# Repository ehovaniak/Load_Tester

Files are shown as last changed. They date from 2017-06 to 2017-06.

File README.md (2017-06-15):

# Load_Tester
This repository contains files and software for a variable load PCB for external load testing and characterization.

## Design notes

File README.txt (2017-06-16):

This repository contains schematics, layout, software, and other data pertaining a siimple load 
testing board I had designed for IV characterization.

This is one of the earliest boards I have designed and manufactured. Load is distrubuted through a 
10-step resistor ladder network. My original implementation adjusts the resistor ladder in a binary 
fashion, allowing for a constant linear increase in current to be drawn from the load. The current 
and voltage are measured by the INA226 IC. Data is managed and transferred over USB to the host 
computer.

I wrote a compaion Python applicaton to interface with the board to adjust load settings manually. I 
also wrote a test function in the app. The test would vary the load from least to greatest and take 
measurements with each load change. Upon completion, the app would plot this data as an IV curve and 
display to the user. The data could also be saved to a .CSV file if desired.

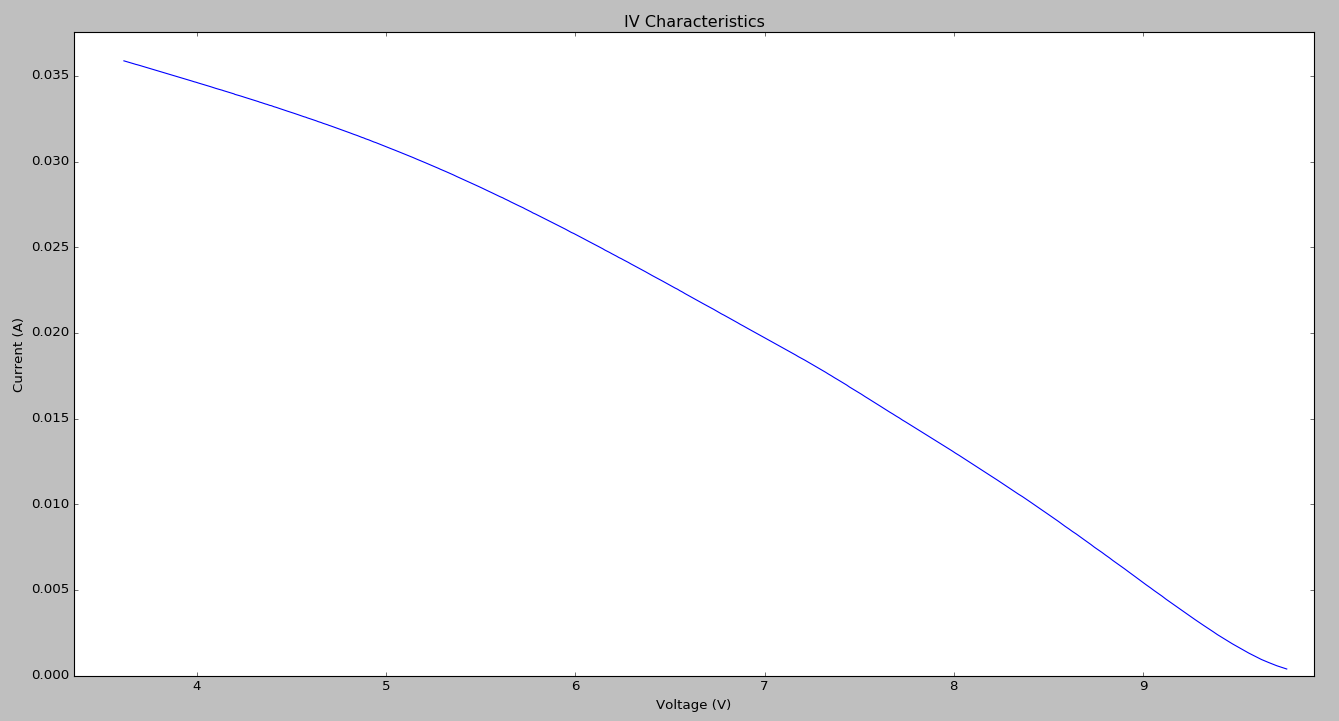
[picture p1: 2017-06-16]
IV_Curve_Example.png

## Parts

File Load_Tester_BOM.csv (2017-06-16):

Designator | Quantity | Description | Manufacturer | Manufacturer Part Number | Supplier | Supplier Part Number
C1 | 1 | CAP CER 4.7UF 35V X5R 0603 | TDK | C1608X5R1V475K080AC | Digi-Key | 445-9064-1-ND
C2 | 1 | CAP CER 22UF 10V X5R 0603 | TDK | C1608X5R1A226M080AC | Digi-Key | 445-9077-1-ND
C3, C5, C10, C14, C16 | 5 | CAP CER 0.1UF 25V X7R 0402 | TDK | C1005X7R1E104K050BB | Digi-Key | 445-7348-1-ND
C4 | 1 | CAP CER 0.1UF 25V X7R 0603 | TDK | C1608X7R1E104K080AA | Digi-Key | 445-1316-1-ND
C6 | 1 | CAP CER 1000PF 50V X7R 0603 | TDK | C1608X7R1H102K080AE | Digi-Key | 445-15923-1-ND
C7 | 1 | CAP CER 10000PF 50V X7R 0603 | TDK | C1608X7R1H103K080AA | Digi-Key | 445-1311-1-ND
C8, C9 | 2 | CAP CER 47PF 50V C0G 0603 | TDK | C1608C0G1H470J080AA | Digi-Key | 445-1277-1-ND
C11, C12 | 2 | CAP CER 18PF 50V C0G 0603 | TDK | CGJ3E2C0G1H180J080AA | Digi-Key | 445-13325-1-ND
C13 | 1 | CAP CER 0.47UF 10V X5R 0402 | TDK | C1005X5R1A474K050BB | Digi-Key | 445-4989-1-ND
C15 | 1 | CAP CER 10UF 10V JB 0603 | TDK | C1608JB1A106K080AC | Digi-Key | 445-11201-1-ND
C17 | 1 | CAP CER 4.7UF 10V X5R 0402 | TDK | C1005X5R1A475K050BC | Digi-Key | 445-13820-1-ND
D1, D2 | 2 | LED SMARTLED GREEN 570NM 0603 | OSRAM Opto Semiconductors | LG L29K-G2J1-24-Z | Digi-Key | 475-2709-1-ND
D3, D4, D5, D6, D7, D8, D9, D10, D11, D12 | 10 | LED SMARTLED RED 630NM 0603 SMD | OSRAM Opto Semiconductors | LS L29K-H1J2-1-Z | Digi-Key | 475-1195-1-ND
J1 | 1 | CONNECTOR MICRO USB B RECPT BTTM MOUNT ASSY | Molex | 47346-0001 | Mouser | 538-47346-0001
J2 | 1 | IDC BOX HEADER 0.050 10 POS | CNC Tech | 3220-10-0300-00 | Digi-Key | 1175-1629-ND
L1, L2 | 2 | FERRITE CHIP 1000 OHM 300MA 0402 | Samsung | CIM05U102NC | Digi-Key | 1276-6336-2-ND
Q1, Q2, Q3, Q4, Q5 | 5 | MOSFET 2N-CH 30V 2A TSMT5 | Rohm Semiconductor | QS5K2TR | Digi-Key | QS5K2CT-ND
R1, R2 | 2 | RES SMD 4.7K OHM 1% 1/10W 0402 | Panasonic | ERJ-2RKF4701X | Digi-Key | P4.70KLCT-ND
R3 | 1 | RES SMD 0.5 OHM 1% 1/8W 0603 | Stackpole Electronics | CSR0603FKR500 | Digi-Key | CSR0603FKR500CT-ND
R4 | 1 | RES SMD 47K OHM 1% 1/10W 0603 | Panasonic | ERJ-3EKF4702V | Digi-Key | P47.0KHCT-ND
R5, R6 | 2 | RES SMD 27 OHM 1% 1/10W 0603 | Panasonic | ERJ-3EKF27R0V | Digi-Key | P27.0HCT-ND
R7 | 1 | RES SMD 1K OHM 5% 1/10W 0603 | Panasonic | ERJ-3GEYJ102V | Digi-Key | P1.0KGCT-ND
R8 | 1 | RES SMD 806 OHM 1% 1/10W 0603 | Panasonic | ERJ-3EKF8060V | Digi-Key | P806HCT-ND
R9 | 1 | RES SMD 51K OHM 1% 1/8W 0805 | Panasonic | ERJ-6ENF5102V | Digi-Key | P51.0KCCT-ND
R10 | 1 | RES SMD 25.5K OHM 1% 1/8W 0805 | Panasonic | ERJ-6ENF2552V | Digi-Key | P25.5KCCT-ND
R11 | 1 | RES SMD 12.7K OHM 1% 1/8W 0805 | Panasonic | ERJ-6ENF1272V | Digi-Key | P12.7KCCT-ND
R12 | 1 | RES SMD 6.2K OHM 1% 1/8W 0805 | Panasonic | ERJ-6ENF6201V | Digi-Key | P6.20KCCT-ND
R13 | 1 | RES SMD 3K OHM 1% 1/8W 0805 | Panasonic | ERJ-6ENF3001V | Digi-Key | P3.0KCCT-ND
R14 | 1 | RES SMD 1K OHM 1% 1/8W 0805 | Panasonic | ERJ-6ENF1001V | Digi-Key | P1.00KCCT-ND
R15 | 1 | RES SMD 150 OHM 1% 1/8W 0805 | Panasonic | ERJ-6ENF1500V | Digi-Key | P150CCT-ND
R16 | 1 | RES SMD 75 OHM 1% 1/8W 0805 | Panasonic | ERJ-6ENF75R0V | Digi-Key | P75.0CCT-ND
R17 | 1 | RES SMD 88.7 OHM 1% 1/8W 0805 | Panasonic | ERJ-6ENF88R7V | Digi-Key | P88.7CCT-ND
R18, R19 | 2 | RES SMD 196 OHM 1% 1/8W 0805 | Panasonic | ERJ-6ENF1960V | Digi-Key | P196CCT-ND
R20 | 1 | RES SMD 604 OHM 1% 1/8W 0805 | Panasonic | ERJ-6ENF6040V | Digi-Key | P604CCT-ND
R21 | 1 | RES SMD 680 OHM 1% 1/2W 0805 | Panasonic | ERJ-P6WF6800V | Digi-Key | P16883CT-ND
R22, R26 | 2 | RES SMD 200 OHM 1% 1/2W 0805 | Panasonic | ERJ-P06F2000V | Digi-Key | P16064CT-ND
R23, R33 | 2 | RES SMD 100 OHM 0.1% 5/8W 0805 | Vishay | PHP00805E1000BST1 | Digi-Key | 764-1114-1-ND
R24, R34 | 2 | DNP | Panasonic | ERJ-6GEY0R00V | Digi-Key | P0.0ACT-ND
R25 | 1 | RES SMD 120 OHM 1% 1/2W 0805 | Panasonic | ERJ-P6WF1200V | Digi-Key | P16874CT-ND
R27, R28, R29, R30, R31, R32, R42, R43, R44, R48 | 10 | RES SMD 750 OHM 1% 1/10W 0603 | Panasonic | ERJ-3EKF7500V | Digi-Key | P750HCT-ND
S1 | 1 | SWITCH TACTILE SPST-NO 0.05A 12V | C&K Components | PTS645SK50SMTR92 LFS | Digi-Key | CKN9087CT-ND
U1 | 1 | IC MONITOR PWR/CURR BIDIR 10MSOP | Texas Instruments | INA226AIDGSR | Digi-Key | 296-29034-1-ND
U2 | 1 | DNP | FTDI | FT231XQ-R | Digi-Key | 768-1128-1-ND
U3 | 1 | DNP | Texas Instruments | MSP430F5132IRSBR | Digi-Key | 296-29345-1-ND
X1 | 1 | CRYSTAL 13.56MHZ 10PF SMD | Abracon | ABM8G-13.560MHZ-4Y-T3 | Digi-Key | 535-10904-1-ND

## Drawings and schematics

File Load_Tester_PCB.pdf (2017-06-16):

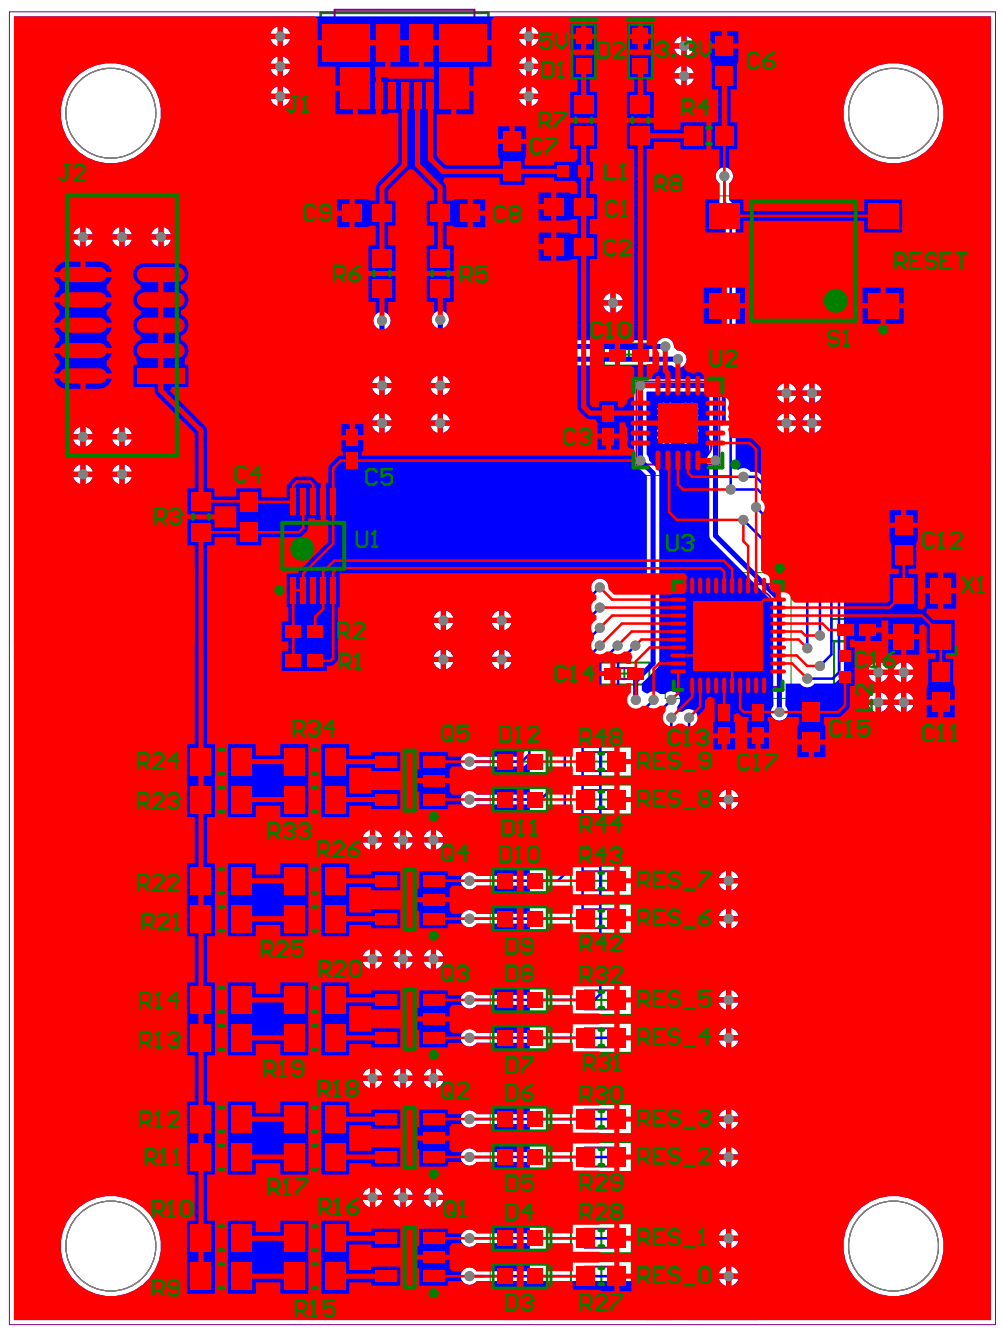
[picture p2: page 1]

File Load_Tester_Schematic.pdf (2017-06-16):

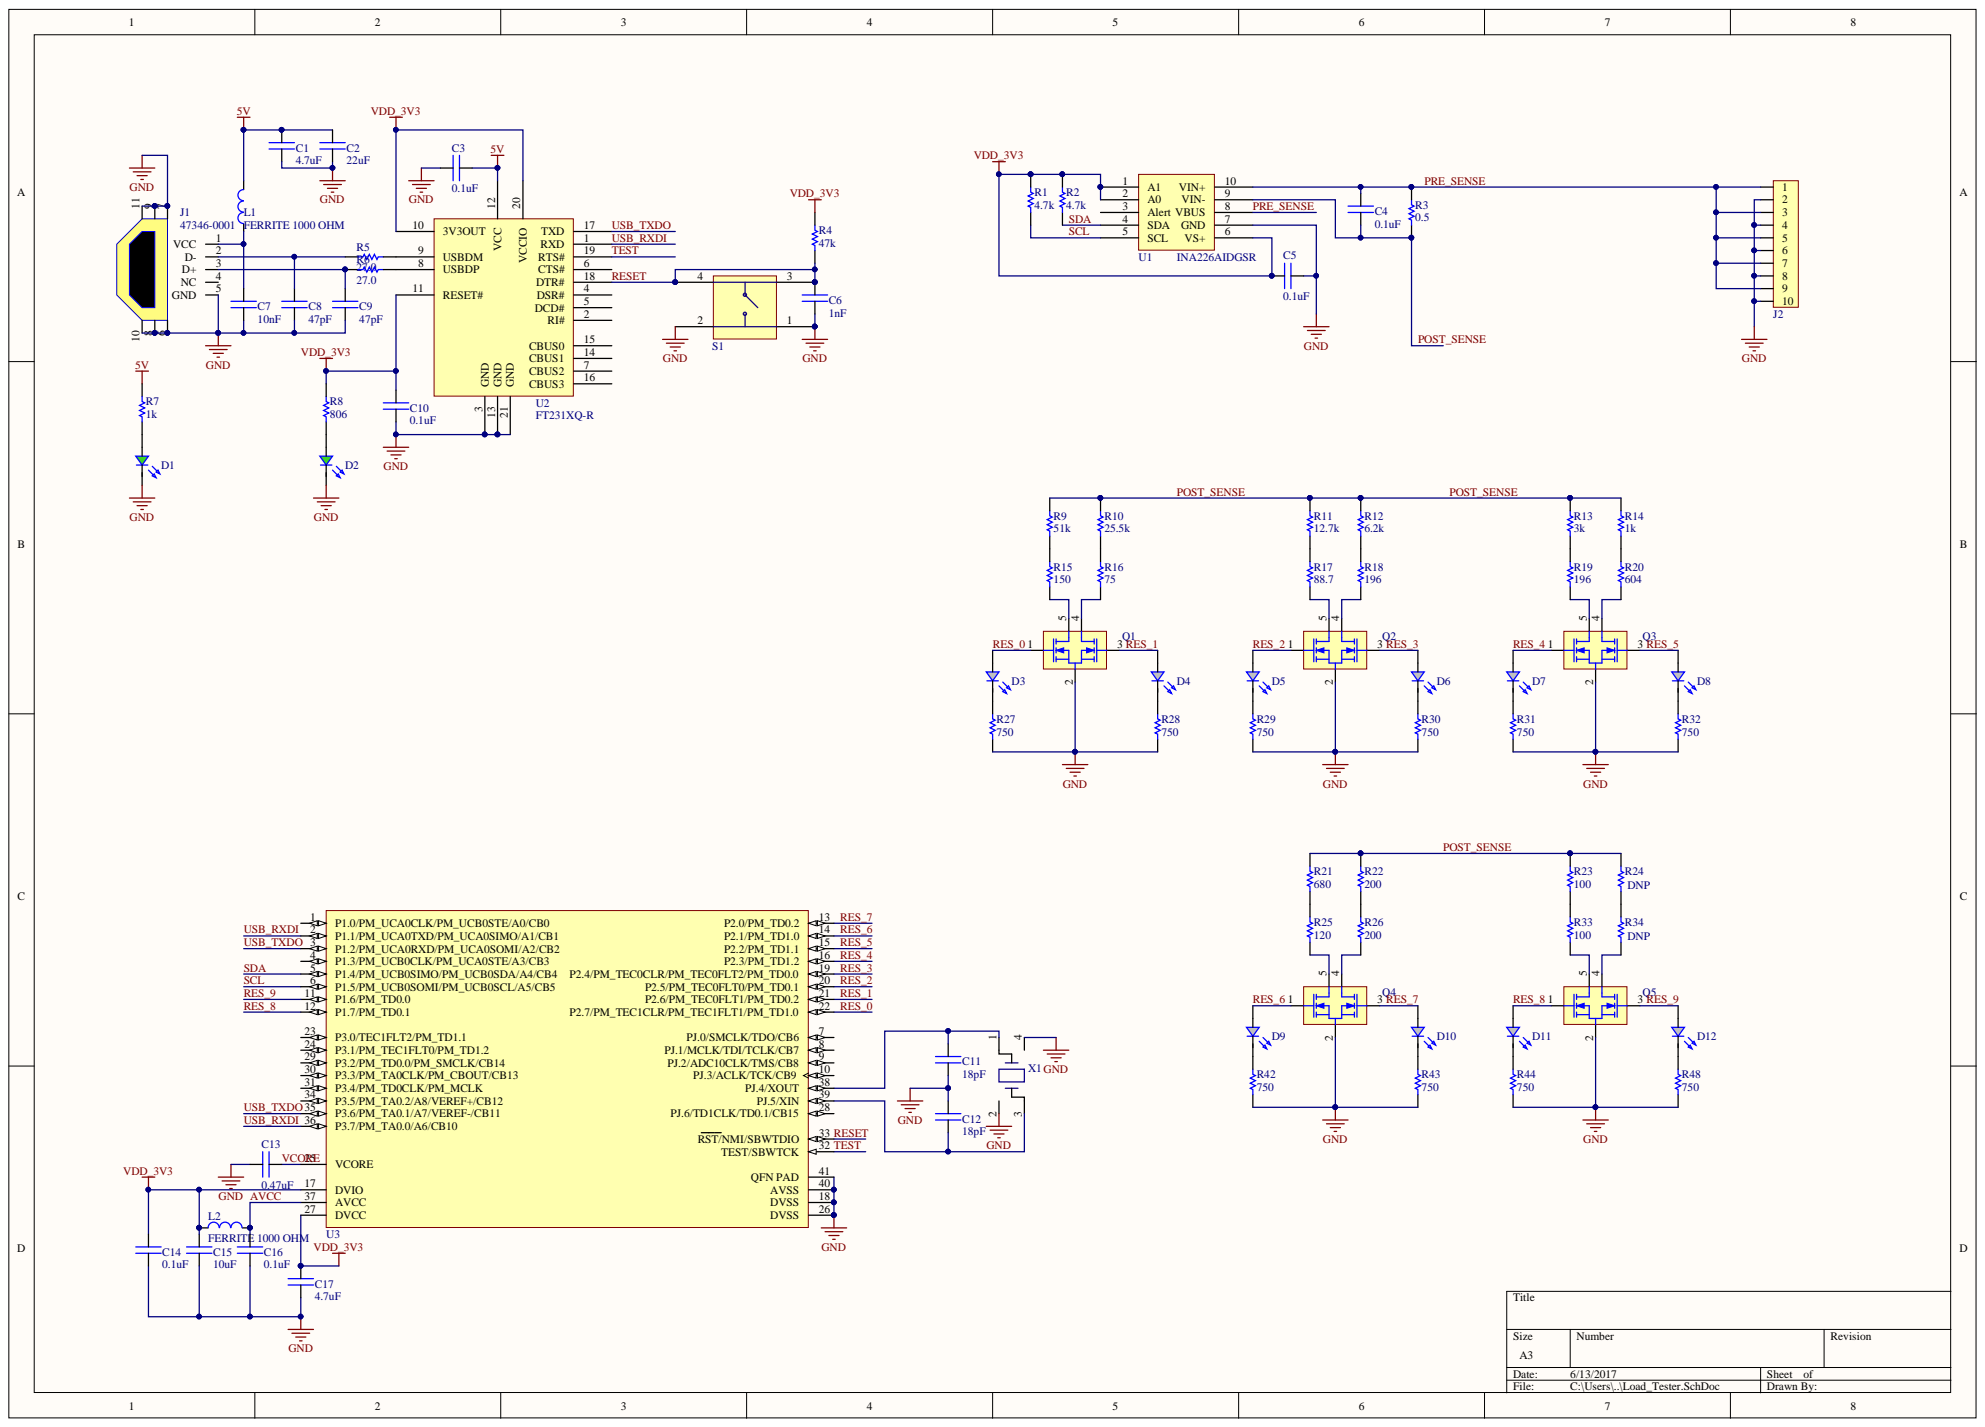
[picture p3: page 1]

A0 2 | 1 2 3 4 5 6 7 8 9 10
Alert 3 | PRE_SENSE

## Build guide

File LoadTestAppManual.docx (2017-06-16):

Load Testing Board/App Instructions:

Background:

The Load Testing Board is a variable load testing fixture to characterize the power capabilities of other assemblies. The fixture configures a parallel resistor network to vary the load seen by the power source under test. Through the app, the user may manually configure the resistor network using the slider utility, or may run a full test which will test the device through all possible load configurations. During the full test, the app pulls the bus voltage and device current for each load configuration, plotting the I-V curve at the conclusion of the test. The user may save this data to a ‘.csv’ file if desired.

Instructions:

1. Plug the Load Tester into an available USB port on your computer. The green ‘5V’ LED and the green ‘3.3V’ LED should immediately turn on.
2. Connect the device you wish to test to connector ‘J2’ using the ribbon cable.
3. On your computer, run ‘LoadTesterApp.exe’. The app should connect to the board and display to your window. If the app fails to load, check the board connections.
4. Check to make sure the ‘Board SN’ field is populated with the correct SN and the ‘Board Rev’ field is populated with the correct board revision. If not, the board may need a FW update.
5. Enter the maximum current you expect to draw from the device under test into the ‘Max Current’ field. This is necessary to set the LSB of the current measurement IC (INA226) on the board. Press the ‘Calculate Calibration’ once entered.
6. Press the ‘Update Device’ button to load the new calibration setting onto the board.
7. Verify the new setting. Move the slider position to the very left and press ‘Set Resistance’ to configure to the lowest load possible.
8. Press ‘Get VBus & Ishunt’ button to pull voltage and current at this low load state. If the ‘Current’ value obtained appears to be maxed to the maximum current you had specified in the ‘Max Current’ field, then you may need to increase the ‘Max Current’ slightly to properly configure the device. Repeat steps 5 & 6 if necessary.
9. Check the ‘Logging’ box if you wish to log the recorded data from the test to a ‘.csv’ file. If yes, enter the name of the file in the ‘Filename’ entry field.
10. Press ‘Run Test’ when ready. The board should begin cycling through all possible load configurations. The app may appear to be frozen during this process. This is normal and the app will respond once the test has concluded.
11. Once the test has concluded, the app will automatically plot the I-V curve of the device under test.
12. To conduct another test, press the ‘Run Test’ button again. The current I-V curve will exit and the test will repeat.

Manual Settings:

- The ‘Slider’ at the top of the ‘Manual Settings’ window is an easy drag tool for configuring the load on the Load Tester. The corresponding load to the slider position is displayed immediately below the slider, in Ohms. The ‘+’ and ‘-‘ buttons to the left and right of the load are fine adjustments of the slider. ‘Inf’ load corresponds to a completely open circuit.
- The ‘Bus Conversion’ drop down menu sets the amount of time the INA226 takes to collect one voltage measurement of the main bus. This feature is useful for timing and noise requirements. A faster conversion time allows for more samples to be taken. A longer conversion time is useful for reducing noise transients.
- The ‘Shunt Conversion’ drop down menu sets the amount of time the INA226 takes to collect one measurement voltage measurement across the shunt resistor. Serves a similar purpose to the ‘Bus Conversion’ drop down menu previously discussed.
- The ‘Num Averages’ drop down menu sets the number of samples the INA226 will take and average for one discrete value. This is useful for noise reduction, but will also increase the time needed for data collection.

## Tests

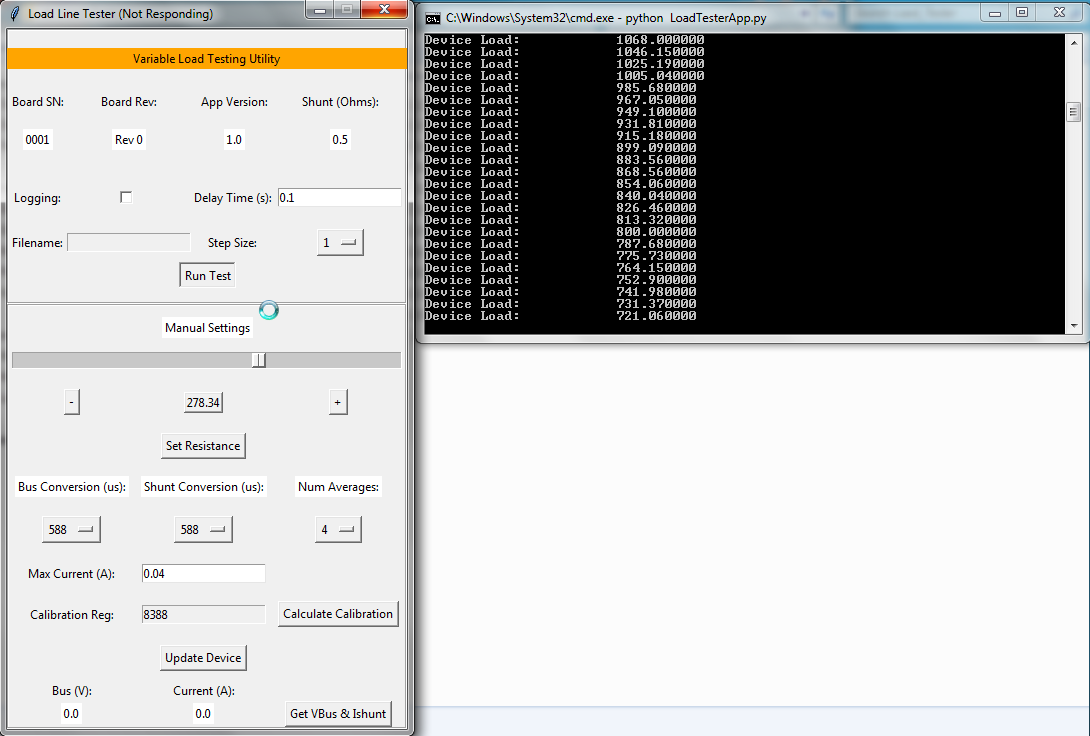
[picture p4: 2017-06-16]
Load_Tester_App.png

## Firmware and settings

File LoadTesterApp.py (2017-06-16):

from tkinter import *
import matplotlib.pyplot as plt
import numpy as np
import datetime
import time
import serial
import serial.tools.list_ports
import itertools
import csv
import tkinter.filedialog

class Application(Frame):
    def __init__(self, master=None):
        self.device = None
        self.good_connection = self.establish_connection()

        if self.good_connection == True:
            Frame.__init__(self, master)
            self.master.grid()
            self.master.title("Load Line Tester")
            self.master.resizable(width=False, height=False)
            self.master.geometry('400x700')

            for r in range(2):
                self.master.rowconfigure(r, weight=1)
            for c in range(1):
                self.master.columnconfigure(c, weight=1)

            self.resistor_discrete = [200.0, 400.0, 800.0, 1604.0, 3196.0, 6396.0, 12788.7, 25575.0, 51150.0]
            self.busTimes = [140, 204, 332, 588, 1100, 2116, 4156, 8244]
            self.shuntTimes = [140, 204, 332, 588, 1100, 2116, 4156, 8244]
            self.numAvgs = [1, 4, 16, 64, 128, 256, 512, 1024]
            self.voltageLSB = 0.00125
            self.maxCal = 32768
            self.res_list = self.resistor_options()
            self.steps = [1, 2, 3, 4, 5, 6, 7, 8, 9, 10]

            self.create_commands_dict()
            self.create_variables()
            #self.get_board_default()

            self.make_frames()
            self.config_autoFrame()
            self.config_debugFrame()

    def create_variables(self):
        self.deviceCal = IntVar()
        self.deviceAvgs = IntVar()
        self.deviceShuntTime = IntVar()
        self.deviceBusTime = IntVar()
        self.deviceBusVolt = DoubleVar()
        self.deviceShuntCurrent = DoubleVar()

        self.filename = StringVar()

        self.boardRev = StringVar()
        self.boardRev.set('Rev 0')
        #self.get_device(self.commands['GET FW VERSION'])

        self.appVersion = StringVar()
        self.appVersion.set('1.0')

        self.sliderControl = IntVar()
        self.sliderControl.set(len(self.res_list) - 1)
        self.resValue = DoubleVar()
        self.deviceRes = DoubleVar()
        self.get_device(self.commands['GET DEVICE RES'])
        self.resValue.set(self.deviceRes.get())

        self.busTimeVar = IntVar()
        self.get_device(self.commands['GET VBUS TIME'])
        self.busTimeVar.set(self.deviceBusTime.get())

        self.shuntTimeVar = IntVar()
        self.get_device(self.commands['GET VSHUNT TIME'])
        self.shuntTimeVar.set(self.deviceShuntTime.get())

        #self.shuntTimeVar.set(self.shuntTimes[0])

        self.numAvgsVar = IntVar()
        self.get_device(self.commands['GET NUM AVGS'])
        self.numAvgsVar.set(self.deviceAvgs.get())

        self.cal = IntVar()
        self.get_device(self.commands['GET CAL REG'])
        self.cal.set(self.deviceCal.get())

        self.shuntRes = DoubleVar()
        self.get_device(self.commands['GET SHUNT'])

        self.maxI = DoubleVar()
        self.maxI.set(self.calculate_maxI(self.cal.get()))
        self.currentLSB = self.maxI.get() / (2**15)

        self.loggingEnable = IntVar()
        self.loggingEnable.set(0)

        self.stepSize = IntVar()
        self.stepSize.set(1)

        self.delayTime = DoubleVar()
        self.delayTime.set(0.1)

    def calculate_maxI(self, cal):
        maxI = (0.00512 * (2 ** 15)) / (cal * self.shuntRes.get())
        maxI = round(maxI, 3)
        return maxI

    def create_commands_dict(self):
        self.commands = dict()
        self.commands['GET FW VERSION'] = '1F'
        self.commands['GET SHUNT'] = '1S'
        self.commands['SET DEVICE RES'] = '3R'
        self.commands['GET DEVICE RES'] = '4R'
        self.commands['SET CAL REG'] = '5C'
        self.commands['GET CAL REG'] = '6C'
        self.commands['SET NUM AVGS'] = '5A'
        self.commands['GET NUM AVGS'] = '6A'
        self.commands['SET VBUS TIME'] = '5B'
        self.commands['GET VBUS TIME'] = '6B'
        self.commands['SET VSHUNT TIME'] = '5S'
        self.commands['GET VSHUNT TIME'] = '6S'
        self.commands['GET VBUS'] = '60'
        self.commands['GET VSHUNT'] = '61'
        self.commands['GET ISHUNT'] = '62'
        self.commands['GET VBUS VSHUNT'] = '63'
        self.commands['GET VBUS ISHUNT'] = '64'

    def establish_connection(self):
        ports = serial.tools.list_ports.comports()
        status = False
        for port in ports:
            if 'LLT' in port[2]:
                p = port[0]
                index = port[2].index('LLT')
                sn = port[2][index:-1]
                status = True
                break

        if status == False:
            print('No Load Line Tester Connected!')
            return status

        self.device = serial.Serial()
        self.device.port = p
        self.device.baudrate = 230400
        self.device.parity = serial.PARITY_NONE
        self.device.stopbits = serial.STOPBITS_ONE
        self.device.bytesize = serial.EIGHTBITS
        self.device.timeout = 0.5
        self.device.write_timeout = 0.5
        self.deviceSN = StringVar()
        self.deviceSN.set('0001')
        #self.deviceSN.set(sn)

        try:
            self.device.open()
        except serial.SerialException:
            print('Error opening port!')
            return False
        time.sleep(0.1)

        self.device.setDTR(False)
        time.sleep(0.1)
        self.device.setDTR(True)
        time.sleep(0.1)
        self.device.setDTR(False)
        time.sleep(0.1)

        self.device.flushInput()
        print("Connected to '%s'" % (self.deviceSN.get()))

        return status

    def resistor_options(self):
        binary = itertools.product([0, 1], repeat=len(self.resistor_discrete))
        binary = list(binary)
        values = []
        for i in range(1, len(binary)):
            value = 0.0
            for j in range(len(self.resistor_discrete)):
                value += (1.0 / self.resistor_discrete[j]) * binary[i][j]
            value = 1.0 / value
            values.append(value)

        values.append(np.float("inf"))

        return sorted(values)

    def get_connection_status(self):
        return self.good_connection

    def calculate_res(self, state):
        value = 0.0
        for i in range(len(self.resistor_discrete)):
            value += (1.0 / self.resistor_discrete[i]) * int(state[i])

        if value == 0.0:
            return np.float("inf")

        return 1.0 / value

    def make_frames(self):
        self.autoFrame = Frame(self.master, bd=2, relief=GROOVE)
        self.autoFrame.grid(row=0, column=0, sticky=W+E+N+S)
        self.debugFrame = Frame(self.master, bd=2, relief=GROOVE)
        self.debugFrame.grid(row=1, column=0, sticky=W+E+N+S)

        for r in range(10):
            self.autoFrame.rowconfigure(r, weight=1)
            self.debugFrame.rowconfigure(r, weight=1)
        for c in range(10):
            self.autoFrame.columnconfigure(c, weight=1)
            self.debugFrame.columnconfigure(c, weight=1)

    def config_autoFrame(self):
        self.filenameLabel = Label(self.autoFrame, text='Filename:')
        self.filenameLabel.grid(row=7, column=0)
        self.filenameEntry = Entry(self.autoFrame, textvariable=self.filename, bg='white', state=DISABLED)
        self.filenameEntry.grid(row=7, column=1)

        self.title = Label(self.autoFrame, text='Variable Load Testing Utility', bg='orange', width=400)
        self.title.place(relx=0.5, rely=0.1, anchor=CENTER)

        self.boardRevLabel1 = Label(self.autoFrame, textvariable=self.boardRev, bg='white')
        self.boardRevLabel1.grid(row=4, column=1)
        self.boardRevLabel2 = Label(self.autoFrame, text='Board Rev:')
        self.boardRevLabel2.grid(row=3, column=1)

        self.boardSNLabel = Label(self.autoFrame, text='Board SN:')
        self.boardSNLabel.grid(row=3, column=0)
        self.boardSNLabel = Label(self.autoFrame, textvariable=self.deviceSN, bg='white')
        self.boardSNLabel.grid(row=4, column=0)

        self.appVersionLabel1 = Label(self.autoFrame, text='App Version:')
        self.appVersionLabel1.grid(row=3, column=2)
        self.appVersionLabel2 = Label(self.autoFrame, textvariable=self.appVersion, bg='white')
        self.appVersionLabel2.grid(row=4, column=2)

        self.shuntResLabel = Label(self.autoFrame, text="Shunt (Ohms):")
        self.shuntResLabel.grid(row=3, column=3)
        self.shuntResLabelVal = Label(self.autoFrame, textvariable=self.shuntRes, bg='white')
        self.shuntResLabelVal.grid(row=4, column=3)

        self.loggingEnableLabel = Label(self.autoFrame, text="Logging:")
        self.loggingEnableLabel.grid(row=6, column=0)
        self.loggingEnableCheck = Checkbutton(self.autoFrame, variable=self.loggingEnable,
                                              command=self.enable_logging)
        self.loggingEnableCheck.grid(row=6, column=1)


        self.delayTimeLabel = Label(self.autoFrame, text="Delay Time (s): ")
        self.delayTimeLabel.grid(row=6, column=2)
        self.delayTimeEntry = Entry(self.autoFrame, textvariable=self.delayTime, bg='white')
        self.delayTimeEntry.grid(row=6, column=3)


        self.stepSizeLabel = Label(self.autoFrame, text="Step Size: ")
        self.stepSizeLabel.grid(row=7, column=2)
        self.stepSizeEntry = OptionMenu(self.autoFrame, self.stepSize, *self.steps)
        self.stepSizeEntry.grid(row=7, column=3)

        self.runTestButton = Button(self.autoFrame, text="Run Test", command=self.run_test)
        self.runTestButton.place(relx=0.5, rely=0.9, anchor=CENTER)

    def config_debugFrame(self):
        self.debugTitle = Label(self.debugFrame, text='Manual Settings', bg='white')
        self.debugTitle.place(relx=0.5, rely=0.05, anchor=CENTER)

        self.sliderResistor = Scale(self.debugFrame, from_=0, to=len(self.res_list) - 1, variable=self.sliderControl,
                                    orient=HORIZONTAL, showvalue=0, command=self.slider_update, length=400,
                                    sliderlength=15, takefocus=0)

        self.sliderResistor.grid(row=2, column=0, columnspan=3)

        self.rightButton = Button(self.debugFrame, text='+', command=self.go_right)
        self.rightButton.grid(row=3, column=2)
        self.leftButton = Button(self.debugFrame, text='-', command=self.go_left)
        self.leftButton.grid(row=3, column=0)
        self.sliderValue = Label(self.debugFrame, textvariable=self.resValue, relief=RAISED)
        self.sliderValue.grid(row=3, column=1)

        self.busTimeDrop = OptionMenu(self.debugFrame, self.busTimeVar, *self.busTimes)
        self.busTimeDrop.grid(row=6, column=0)
        self.busTimeLabel = Label(self.debugFrame, text='Bus Conversion (us):', bg='white')
        self.busTimeLabel.grid(row=5, column=0)

        self.shuntTimeDrop = OptionMenu(self.debugFrame, self.shuntTimeVar, *self.shuntTimes)
        self.shuntTimeDrop.grid(row=6, column=1)
        self.shuntTimeLabel = Label(self.debugFrame, text='Shunt Conversion (us):', bg='white')
        self.shuntTimeLabel.grid(row=5, column=1)

        self.numAvgsDrop = OptionMenu(self.debugFrame, self.numAvgsVar, *self.numAvgs)
        self.numAvgsDrop.grid(row=6, column=2)
        self.numAvgsLabel = Label(self.debugFrame, text='Num Averages:', bg='white')
        self.numAvgsLabel.grid(row=5, column=2)

        self.maxIEntry = Entry(self.debugFrame, textvariable=self.maxI, bg='white')
        self.maxIEntry.grid(row=7, column=1)
        self.maxILabel = Label(self.debugFrame, text="Max Current (A):")
        self.maxILabel.grid(row=7, column=0)
        self.calEntry = Entry(self.debugFrame, textvariable=self.cal, bg='white', state='readonly')
        self.calEntry.grid(row=8, column=1)
        self.calLabel = Label(self.debugFrame, text="Calibration Reg:")
        self.calLabel.grid(row=8, column=0)
        self.calButton = Button(self.debugFrame, text="Calculate Calibration", command=self.calculate_cal,
                                relief=RAISED)
        self.calButton.grid(row=8, column=2)

        self.updateDeviceButton = Button(self.debugFrame, text="Update Device", command=self.update_device,
                                         relief=RAISED)
        self.updateDeviceButton.grid(row=9, column=1)
        self.updateResistanceButton = Button(self.debugFrame, text="Set Resistance", command=self.set_res,
                                             relief=RAISED)
        self.updateResistanceButton.grid(row=4, column=1)

        self.getVbusIshuntButton = Button(self.debugFrame, text='Get VBus & Ishunt',
                                          command=lambda: self.get_device(self.commands['GET VBUS ISHUNT']))
        self.getVbusIshuntButton.grid(row=12, column=2)
        self.getVbusIshuntLabelV = Label(self.debugFrame, textvariable=self.deviceBusVolt, bg='white')
        self.getVbusIshuntLabelV.grid(row=12, column=0)
        self.getVbusIshuntLabelI = Label(self.debugFrame, textvariable=self.deviceShuntCurrent, bg='white')
        self.getVbusIshuntLabelI.grid(row=12, column=1)

        self.vbusLabel = Label(self.debugFrame, text='Bus (V):')
        self.vbusLabel.grid(row=11, column=0)
        self.currentLabel = Label(self.debugFrame, text='Current (A):')
        self.currentLabel.grid(row=11, column=1)

    def res_int_to_hex(self, num):
        hexRes = hex(num).upper()[2:]
        while len(hexRes) < 4:
            hexRes = '0' + hexRes
        newHexRes = ''
        for i in range(len(hexRes)):
            newHexRes = newHexRes + hex(~int(hexRes[i], 16) + 16).upper()[2:]
        binaryRes = bin(int(newHexRes, 16))[2:]
        binaryRes = list(binaryRes)
        for i in range(len(binaryRes)):
            if i < 7:
                binaryRes[i] = '0'
        byteLow = binaryRes[8:]
        byteHigh = binaryRes[0:8]
        newBinaryRes = byteHigh[::-1] + byteLow[::-1]
        newBinaryRes = ''.join(newBinaryRes)
        hexRes = hex(int(newBinaryRes, 2)).upper()[2:]
        while len(hexRes) < 4:
            hexRes = '0' + hexRes
        hexRes = self.commands['SET DEVICE RES'] + hexRes

        return hexRes

    def set_res(self):
        hexRes = self.res_int_to_hex(self.sliderControl.get())
        try:
            self.device.write(hexRes.encode('ASCII'))
        except serial.serialutil.SerialException:
            print('Device Disconnected!')
            return

        time.sleep(0.001)
        self.get_device(self.commands['GET DEVICE RES'])
        print('Requested Load (Ohms):\t\t%f' % (round(self.resValue.get(), 2)))
        print('Device Load (Ohms):\t\t\t%f' % (round(self.deviceRes.get(), 2)))
        print()

    def enable_logging(self):
        if self.loggingEnable.get() == 1:
            self.filenameEntry.config(state=NORMAL)
        else:
            self.filenameEntry.config(state=DISABLED)

    def run_test(self):
        plt.close('all')

        self.get_device(self.commands['GET VBUS ISHUNT'])

        data = []
        self.device.write((self.commands['SET DEVICE RES'] + '0000').encode('ASCII'))
        self.get_device(self.commands['GET DEVICE RES'])
        print('Device Load:\t\t%f' % (self.deviceRes.get()))
        for j in range(len(self.res_list) - 2, -1, -self.stepSize.get()):
            hexRes = self.res_int_to_hex(j)
            try:
                self.device.write(hexRes.encode('ASCII'))
                time.sleep(self.delayTime.get())
                self.get_device(self.commands['GET VBUS ISHUNT'])
                self.get_device(self.commands['GET DEVICE RES'])
                print('Device Load:\t\t%f' % (self.deviceRes.get()))
                #print(self.stepSize.get())
                #print(self.delayTime.get())
                temp = [self.deviceRes.get(), self.deviceBusVolt.get(), self.deviceShuntCurrent.get(), self.deviceAvgs.get(), self.deviceBusTime.get(), self.deviceShuntTime.get()]
                data.append(temp)
            except serial.serialutil.SerialException:
                print('Device Disconnected!')
                return

            #print(j)


        self.device.write((self.commands['SET DEVICE RES'] + '0000').encode('ASCII'))

        if self.loggingEnable.get() == 1 and len(data) > 0:
            if len(self.filename.get()) == 0:
                currentDateTime = datetime.datetime.now()
                hour = str(currentDateTime.hour)
                minute = str(currentDateTime.minute)
                second = str(currentDateTime.second)
                year = str(currentDateTime.year)
                day = str(currentDateTime.day)
                month = str(currentDateTime.month)

                if len(hour) < 2:
                    hour = '0' + hour
                if len(minute) < 2:
                    minute = '0' + minute
                if len(second) < 2:
                    second = '0' + second
                if len(day) < 2:
                    day = '0' + day
                if len(month) < 2:
                    month = '0' + month

                filename = 'Load_Test_' + month + day + year + '_' + hour + minute + second + '.csv'
            else:
                filename = self.filename.get() + '.csv'

            with open(filename, 'w', newline='') as file:
                logging = csv.writer(file, delimiter=',')
                logging.writerow(["Resistance (Ohms)", "VBus (V)", "IShunt (A)", "Averages", "VBus Conversion Time (us)", "IShunt Conversion Time (us)"])
                logging.writerows(data)

        if len(data) > 0:
            plt.figure("IV Characteristics")
            plt.title("IV Characteristics")
            temp1 = []
            temp2 = []
            for i in range(1, len(data)):
                temp1.append(data[i][1])
                temp2.append(data[i][2])
            plt.plot(temp1, temp2)
            plt.xlabel('Voltage (V)')
            plt.ylabel('Current (A)')
            plt.show()

    def slider_update(self, *args):
        if args[0] == str(len(self.res_list) - 1):
            self.resValue.set(np.float("inf"))
        else:
            self.resValue.set(round(self.res_list[int(args[0])], 2))

    def go_right(self):
        index = self.sliderControl.get()
        if index < len(self.res_list) - 1:
            index += 1
            self.sliderControl.set(index)
            if index == len(self.res_list) - 1:
                self.resValue.set(np.float("inf"))
            else:
                self.resValue.set(round(self.res_list[index], 2))

    def go_left(self):
        index = self.sliderControl.get()
        if index > 0:
            index -= 1
            self.sliderControl.set(index)
            self.resValue.set(round(self.res_list[index], 2))

    def calculate_cal(self):
        currentLSB = self.maxI.get() / (2**15)
        cal = int(0.00512 / (currentLSB * self.shuntRes.get()))
        if cal >= self.maxCal:
            maxIReset = self.calculate_maxI(self.cal.get())
            self.maxI.set(maxIReset)
            print('Calibration Register overflow! Max Current is too small!')
            print()
            return

        self.currentLSB = currentLSB
        self.cal.set(cal)

    def get_device(self, cmd):
        try:
            self.device.write(cmd.encode('ASCII'))
            read = self.device.readline().decode('ASCII')
        except serial.serialutil.SerialException:
            print('Device Disconnected!')
            return

        read = read.strip('\r\n')

        if read == '<< BAD COMMAND! >>':
            #print(cmd)
            print('<< BAD COMMAND! >>')
            return
        elif not len(read) > 0:
            print('Invalid Receipt! Check Device FW')
            return
        elif cmd == self.commands['GET FW VERSION']:
            self.boardRev.set(read)
        elif cmd == self.commands['GET SHUNT']:
            self.shuntRes.set(float(read))
        elif cmd == self.commands['GET VBUS ISHUNT']:
            read1 = read[0:4]
            read2 = read[5:]
            read1 = int(read1, 16)
            read2 = int(read2, 16)
            self.deviceBusVolt.set(read1 * self.voltageLSB)
            self.deviceShuntCurrent.set(read2 * self.currentLSB)
        else:
            read = int(read, 16)

            if cmd == self.commands['GET NUM AVGS']:
                self.deviceAvgs.set(read)
            elif cmd == self.commands['GET VBUS TIME']:
                self.deviceBusTime.set(read)
            elif cmd == self.commands['GET CAL REG']:
                self.deviceCal.set(read)
            elif cmd == self.commands['GET VSHUNT TIME']:
                self.deviceShuntTime.set(read)
            elif cmd == self.commands['GET VBUS']:
                self.deviceBusVolt.set(read * self.voltageLSB)
            elif cmd == self.commands['GET ISHUNT']:
                self.deviceShuntCurrent.set(read * self.currentLSB)
            elif cmd == self.commands['GET DEVICE RES']:
                binary = bin(read)[2:]
                while len(binary) < 16:
                    binary = '0' + binary
                binary = binary[0] + (binary[8:])[::-1]
                read = round(self.calculate_res(binary), 2)
                self.deviceRes.set(read)

    def update_device(self):
        cal = hex(self.cal.get()).upper()[2:]
        while len(cal) < 4:
            cal = '0' + cal
        cal = self.commands['SET CAL REG'] + cal

        avg = hex(self.numAvgsVar.get()).upper()[2:]
        while len(avg) < 4:
            avg = '0' + avg
        avg = self.commands['SET NUM AVGS'] + avg

        busTime = hex(self.busTimeVar.get()).upper()[2:]
        while len(busTime) < 4:
            busTime = '0' + busTime
        busTime = self.commands['SET VBUS TIME'] + busTime

        shuntTime = hex(self.shuntTimeVar.get()).upper()[2:]
        while len(shuntTime) < 4:
            shuntTime = '0' + shuntTime
        shuntTime = self.commands['SET VSHUNT TIME'] + shuntTime
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
